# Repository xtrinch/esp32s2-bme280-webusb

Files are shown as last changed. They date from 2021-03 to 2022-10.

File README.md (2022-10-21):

# esp32s2-bme280-webusb

Sends periodic `bme280` humidity, temperature, pressure and battery voltage data from `esp32s2 development board` to [sensor dashboard](http://iotfreezer.com) backend via Wi-Fi. 

Is configurable via a [web interface](http://iotfreezer.com/) using webusb. Since the board uses native usb communication, the serial output will also be emulated via USB so it may not work as you would expect a regular serial connection - if it's configured wrongly, there will be no output in your serial monitor. If the board sleeps, when you connect it to USB, you will not be able to flash it. Board needs to be wide awake and listening to USB commands for flashing to work. When the board is connected to the computer - the neopixel of the esp32s2 will light up and the display should display `PC` instead of the usual measurements.

If you botch the code and manage to put it to sleep when on USB, boot the board into bootloader mode by holding the button `BUT1` on the board when connecting to USB, then you will be able to flash via USB again.

Currently, this firmware can make it around 7 months on a 1200mA battery connected to the dev board. The board can be configured to send the measurements to the server once every N times via the parameter `maxRtcRecords` to optimize battery time.

Built with PlatformIO.

See also [backend](https://github.com/xtrinch/sensor-dashboard-nestjs-backend) and [frontend](https://github.com/xtrinch/sensor-dashboard-react-frontend) repo, or [see it live](http://iotfreezer.com/) with some sensor data from my living room.

## Components
- ESP32S2 dev board with native usb support, meaning there should not be a usb to serial converter on the board, I used [ESP32-S2-DevKit-Lipo-USB from Olimex](https://www.olimex.com/Products/IoT/ESP32-S2/ESP32-S2-DevKit-Lipo-USB/open-source-hardware)
- Waveshare e-paper 1.54inch display - black and white version
- Bosch BME280 sensor module
- 3.7V LiPo battery (or other), e.g. [BATTERY-LIPO1400mAh from Olimex](https://www.olimex.com/Products/Power/BATTERY-LIPO1400mAh/)

## Additional things needed to assemble the PCB
- PH2.0 8 pin connectors for the display (bent needle for the PCB)
- min 2, max 4 2.0mm high spacers to mount the display above the ESP32S2, depending on how many sides of the display you want to fixate
- PH2.0 2pin connector for the battery (if the battery doesn't already come with one)
- bunch of male / female headers
- 1x push button - right angled for RESET button
- 1x push button - regular for BOOT button

## Setup

1. Have a sensor dashboard backend running (see https://github.com/xtrinch/sensor-dashboard-nestjs-backend) or use [iotfreezer](http://iotfreezer.com/).
2. remove the solder from `LED1_ENABLE SMD` jumper (i.e. open it) on the ESP32S2, because it consumes a large current 
3. solder the `BAT_SENS` and `PWR_SENS` jumpers on the ESP32S2, to be able to detect battery voltage levels
4. Uncomment the part in `main.cpp` that routes VREF to a GPIO on the ESP32S2. Program the board, measure VREF and input it into `import_env.py` under `REF_VOLTAGE` (if it's e.g. 1.1, input 1100). This will be needed for accurate battery measurement and you cannot skip this step.
5. Copy `import_env.example.py` to `import_env.py` and define your sensor dashboard url.
6. Run `pio run -t buildfs && pio run -t uploadfs` to upload the icons the display uses for humidity/temperature
7. While having your board plugged into the computer, reboot the board and configure it via the web interface (via webusb) of the sensor dashboard (iotfreezer).

## Troubleshooting

If you cannot upload to your board on linux, input `sudo chmod a+rw /dev/ttyUSB0`.

To monitor across reboots, as uploading and monitoring does not work, use the following command on Linux:
`while [ true ]; do cat /dev/ttyACM0; done`
 
To check out the usb descriptors, run `lsusb -v`. To check out the kernel logs for errors, run `dmesg`.
## Convert icons

 `convert temperature-2-48.png -background white -alpha remove -alpha off -compress none -depth 24 -resize 48x48 temp-final.bmp`

## Production deploy

Make sure to turn off `DEBUG` to save power.

## PCB

See `schematics-w-display` folder for full project. It was drawn in KiCad and it's a two sided PCB.

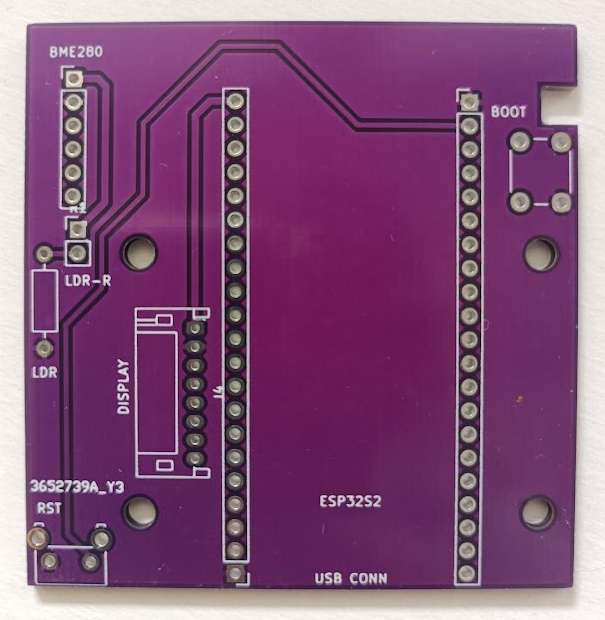
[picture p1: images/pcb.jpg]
Image of Yaktocat


## End product with casing

Casing is parametric and drawn in FreeCad 0.19. It is made to fit the above PCB. For FreeCad project, see `casing-w-display` folder.

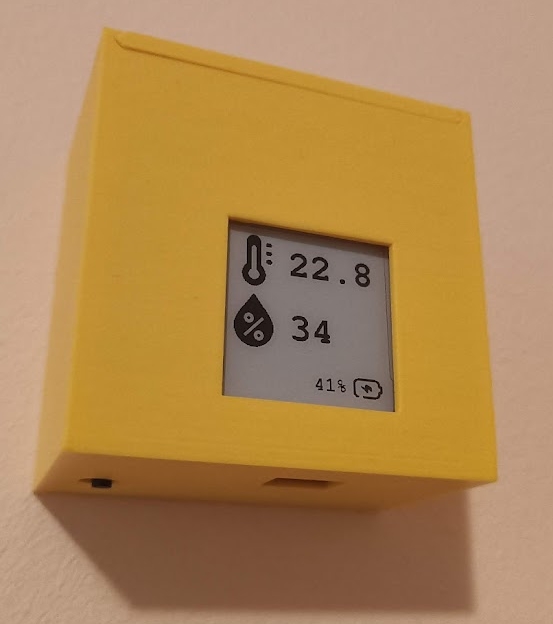
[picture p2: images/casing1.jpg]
Image of Yaktocat

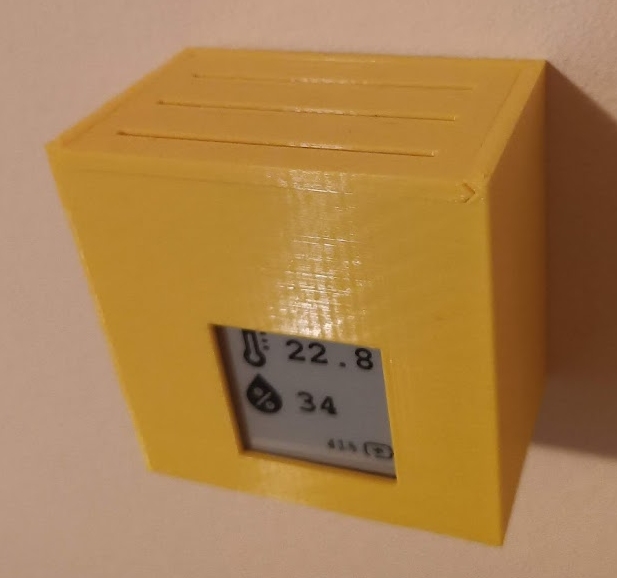
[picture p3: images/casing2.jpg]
Image of Yaktocat


# TODOs
- use ULP to use power pin as ADC wakeup source
- reference ADC voltage to parametrizable params?

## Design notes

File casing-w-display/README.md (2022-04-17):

# parametric display casing

Parametric display casing drawn in FreeCAD.

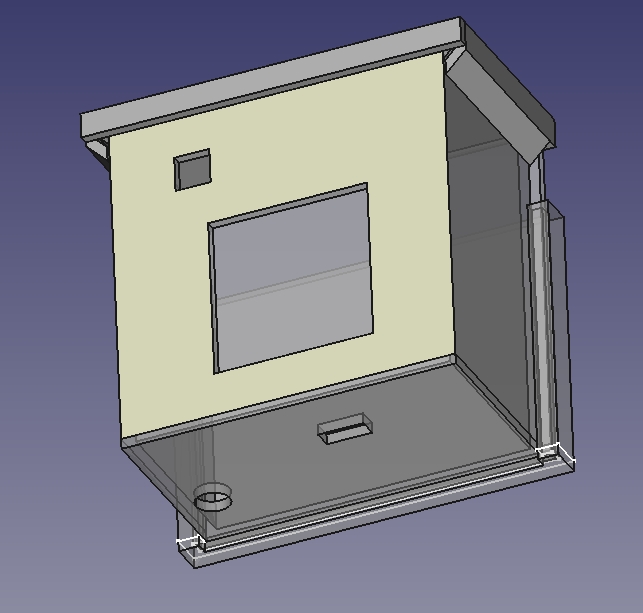
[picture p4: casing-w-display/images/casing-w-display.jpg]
Image of Yaktocat


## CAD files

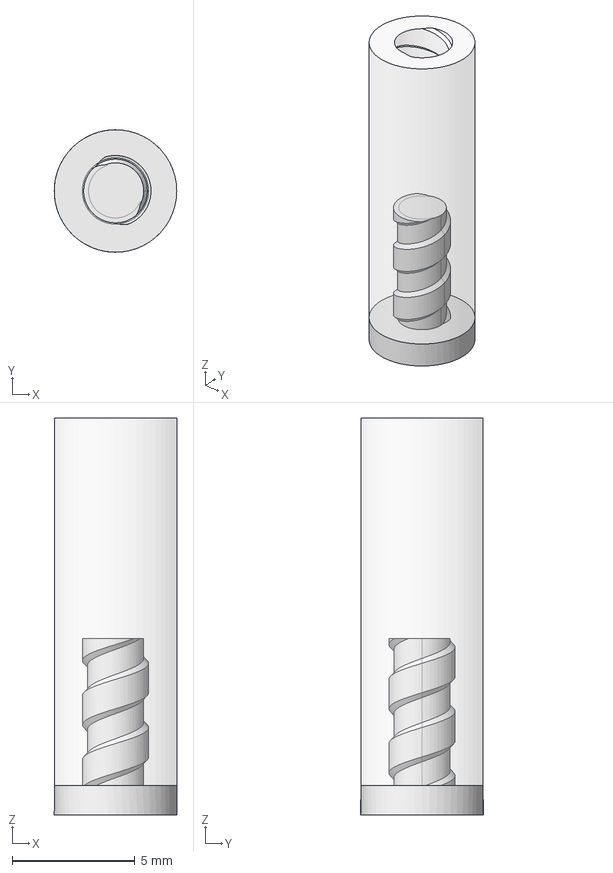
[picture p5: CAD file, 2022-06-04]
casing-w-display/display-spacers.FCStd
5.00 x 5.00 x 16.2 mm
Display spacer
Screw

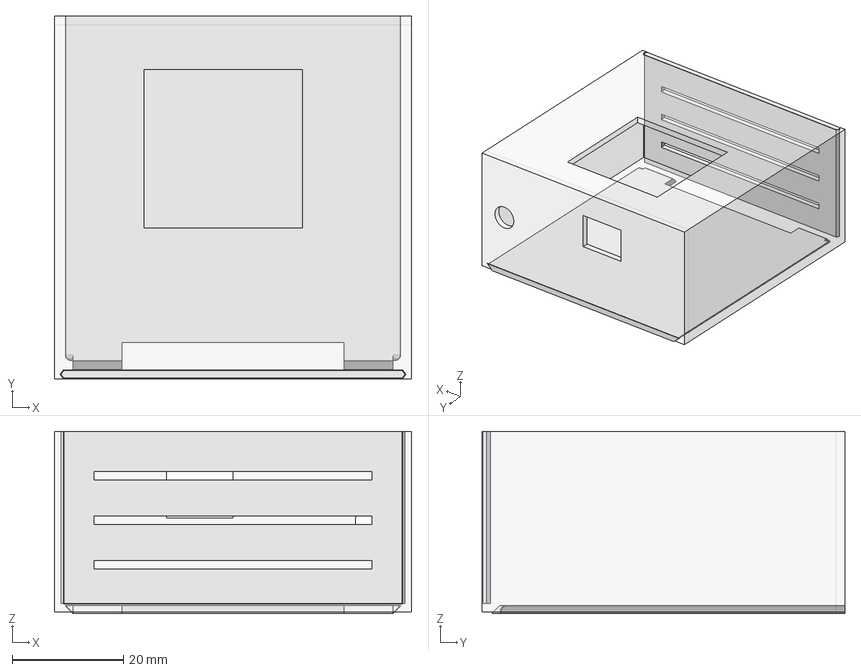
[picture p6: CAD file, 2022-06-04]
casing-w-display/display-casing.FCStd
64.2 x 65.2 x 32.8 mm
Lid
WallMount

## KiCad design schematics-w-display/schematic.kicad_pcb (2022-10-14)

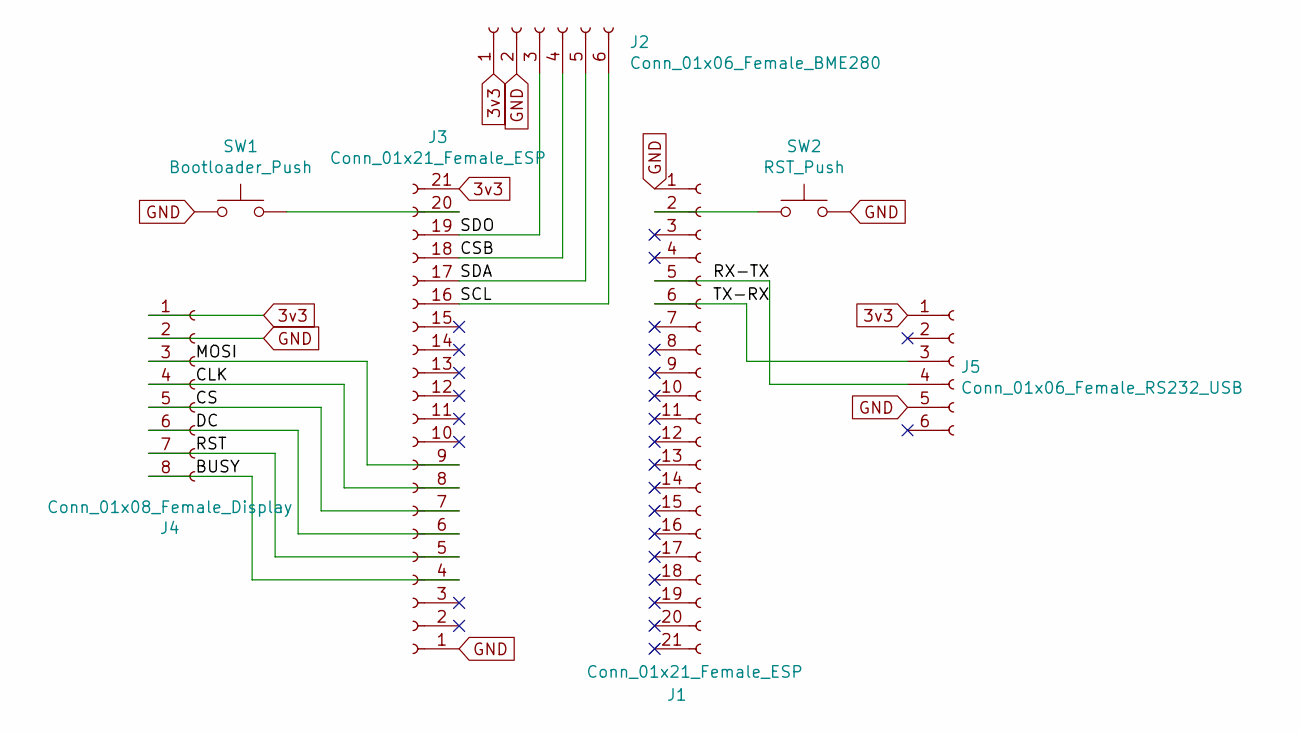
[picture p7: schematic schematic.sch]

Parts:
J1, J3: Conn_01x21_Female_ESP; PinHeader_1x21_P2.54mm_Vertical
J2: Conn_01x06_Female_BME280; PinHeader_1x06_P2.54mm_Vertical
J4: Conn_01x08_Female_Display; JST_PH_S8B-PH-K_1x08_P2.00mm_Horizontal
J5: Conn_01x06_Female_RS232_USB; PinHeader_1x06_P2.54mm_Vertical
SW1: Bootloader_Push; SW_PUSH_6mm
SW2: RST_Push; SW_Tactile_SKHH_Angled

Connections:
3v3: J2.1, J3.21, J4.1, J5.1
/BUSY: J3.4, J4.8
/CLK: J3.8, J4.4
/CS: J3.7, J4.5
/CSB: J2.4, J3.18
/DC: J3.6, J4.6
/MOSI: J3.9, J4.3
/RST: J3.5, J4.7
/RX-TX: J1.5, J5.4
/SCL: J2.6, J3.16
/SDA: J2.5, J3.17
/SDO: J2.3, J3.19
/TX-RX: J1.6, J5.3
GND: J1.1, J2.2, J3.1, J4.2, J5.5, SW1.1, SW2.2
unnamed: J1.2, SW2.1
unnamed: J3.20, SW1.2

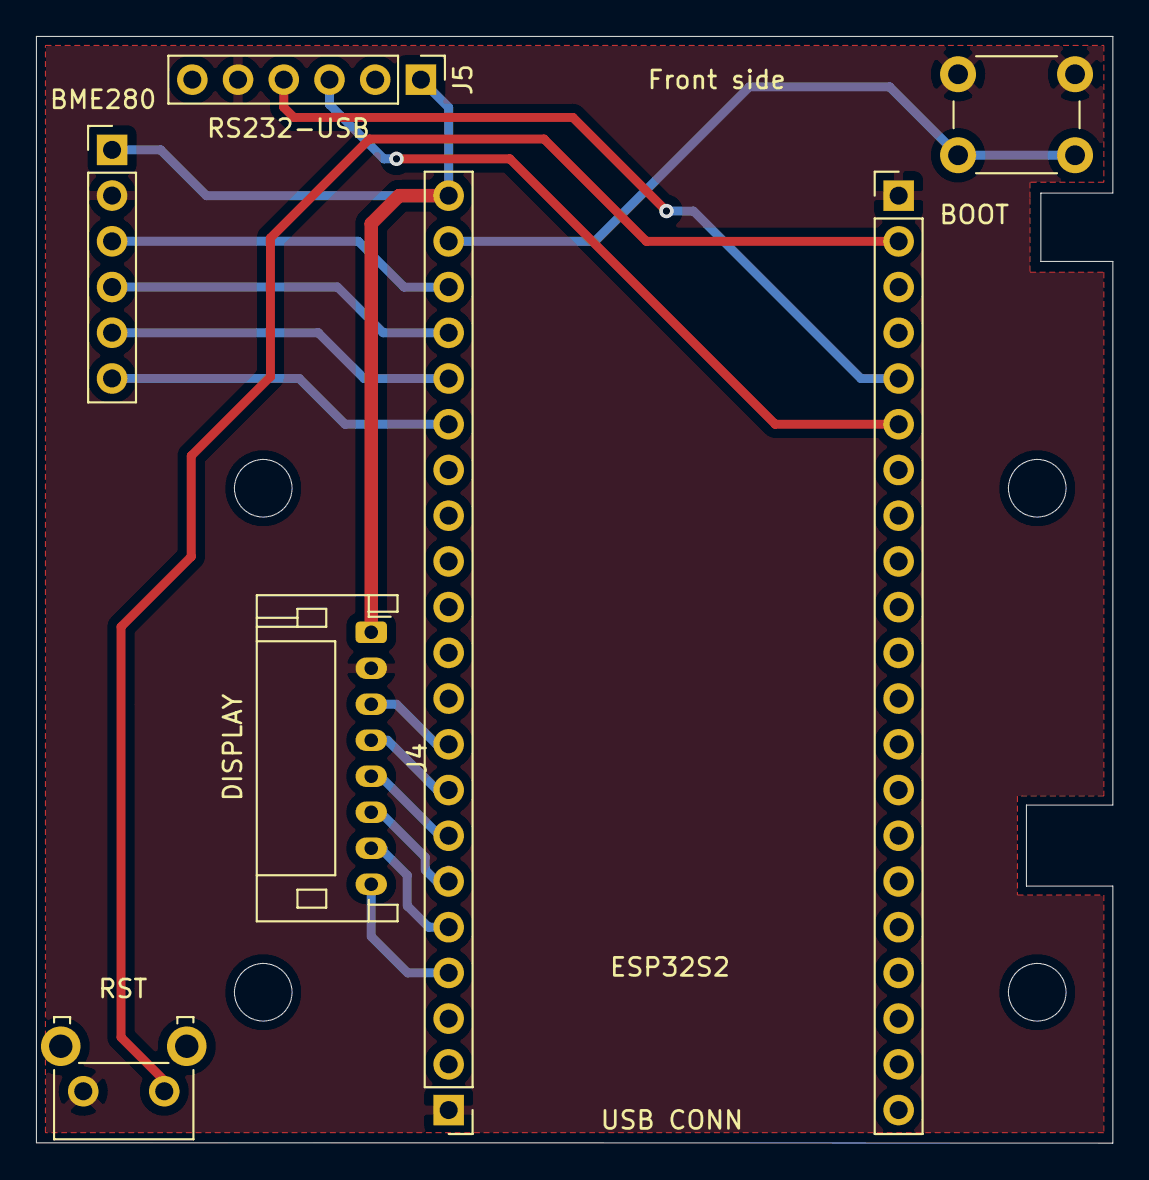
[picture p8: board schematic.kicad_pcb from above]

Board: 2 copper layers, 59.8 x 61.5 mm, 10 parts (0 on the bottom side), 16 nets.

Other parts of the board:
 : MountingHole_3.2mm_M3_DIN965
 #2,  #3: MountingHole_3.2mm_M3_DIN965

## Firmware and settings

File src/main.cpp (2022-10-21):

#include "main.h"
#include "esp_adc_cal.h"

RTC_DATA_ATTR int recordCounter = 0;
RTC_DATA_ATTR bme280record records[100]; // max 100, actual defined by config

#define NEOPIXEL_PIN 18
#define NUMPIXELS 1

Adafruit_NeoPixel pixels(NUMPIXELS, NEOPIXEL_PIN, NEO_GRB + NEO_KHZ800);

WebUSB WebUSBSerial;
CDCusb USBSerial;
Preferences preferences;

volatile bool usbConnected = 0;

// in-sane defaults, which shouldn't be used
// if there's no user configuration anyway
int maxRtcRecords = 1; // always send
int sleepInMinutes = 1; // send once per minute

class MyWebUSBCallbacks: public WebUSBCallbacks {
    void onConnect(bool state) {
      usbConnected = true;
      ardprintf("webusb is %s\n", state ? "connected":"disconnected");
    }
};

class MyCDCUSBCallbacks: public CDCCallbacks {
  // when a serial monitor connects
  bool onConnect(int itf, bool dtr, bool rts) {
    ardprintf("Connected, dtr: %d, rts: %d, itf: %d", dtr, rts, itf);
    usbConnected = true;
    return true;
  }
  void onData() { 
    ardprintf("Received");
    usbConnected = true;
  }
  void onCodingChange(cdc_line_coding_t const* p_line_coding) { 
    ardprintf("C:");
    usbConnected = true;
  }
};

class MyUSBCallbacks: public USBCallbacks {
  void onMount() {
    ardprintf("Mounted");
    usbConnected = true;
  }
};

void sleep(bool forever = false) {
  goToSleep(sleepInMinutes*60, forever);
}

esp_adc_cal_characteristics_t *adc_chars = new esp_adc_cal_characteristics_t;

void setup() {
  WiFi.mode(WIFI_MODE_NULL);

  esp_sleep_wakeup_cause_t wakeup_reason = esp_sleep_get_wakeup_cause();
  bool isReset = wakeup_reason != ESP_SLEEP_WAKEUP_TIMER;

  // this can stay, even if we're not using serial
  Serial.begin(115200);

  USBSerial.setCallbacks(new MyCDCUSBCallbacks());

  WebUSBSerial.landingPageURI("iotfreezer.com", true);
  WebUSBSerial.deviceID(0x2341, 0x0002);
  WebUSBSerial.setCallbacks(new MyWebUSBCallbacks());

  EspTinyUSB::registerDeviceCallbacks(new MyUSBCallbacks());

  if(!USBSerial.begin()) {
    ardprintf("Failed to start USB stack");
    return;
  }

  if(!WebUSBSerial.begin()) {
    ardprintf("Failed to start webUSB stack");
    return;
  }

  pinMode(BAT_SENS_PIN, INPUT_PULLDOWN);
  pinMode(PWR_SENS_PIN, INPUT_PULLDOWN);

  // calibrate the ADC with the measured VREF at 0 attenuation
  adc1_config_width(ADC_WIDTH_BIT_13);
  adc1_config_channel_atten(ADC1_CHANNEL_7, ADC_ATTEN_DB_0); // TODO: channels should be parametrized from pin number
  esp_adc_cal_value_t val_type = 
    esp_adc_cal_characterize(ADC_UNIT_1, ADC_ATTEN_DB_0, ADC_WIDTH_BIT_13, REF_VOLTAGE, adc_chars);

  // IMPORTANT:
  // Uncomment, when you want to route VREF to a GPIO to measure it with a multimeter
  // routeVRefToGPIO(ADC_UNIT_1, GPIO_NUM_17);

  adc1_config_channel_atten(ADC1_CHANNEL_6, ADC_ATTEN_DB_0);
  double rawAdcPower = adc1_get_raw(ADC1_CHANNEL_6);   // read the input pin, 8129 max
  double vPowerMeasured = esp_adc_cal_raw_to_voltage(rawAdcPower, adc_chars);
  double vPower = ((vPowerMeasured/1000.0) * (1000+10000)) / 1000.0; // voltage divider equation
  
  bool connectedToPower = false;
  if (vPower > 3.0) {
    // as an alternative, this could be used for usb connected status, but
    // it would also fire when charging via a regular outlet
    connectedToPower = true;
  }

  double rawAdcBatteryVal = adc1_get_raw(ADC1_CHANNEL_7);
  double vBatMeasured = esp_adc_cal_raw_to_voltage(rawAdcBatteryVal, adc_chars);
  double vBat = ((vBatMeasured/1000.0) * (470000+4700000)) / 470000.0;

  pixels.begin();
  pixels.clear();
  pixels.show();

  if (isCfgSaved()) {
    preferences.begin("iotfreezer", true);
    maxRtcRecords = preferences.getInt("max_rtc_records");
    sleepInMinutes = preferences.getInt("time_between");
    ardprintf("Read max_rtc_records: %d", maxRtcRecords);
    ardprintf("Read time_between: %d", sleepInMinutes);
    preferences.end();
  }

  // wait if usb connection appears - we're supposed to reset the controller when connecting to pc
  // - below 500 won't work
  if ((isReset && ENABLE_USB_CONFIGURATOR)) {
    // we can afford to wait a little longer since we know that the
    // connected to power works well
    delay(1500);
    ardprintf("Connected!. Power is raw %f, measured %f, calculated %f", rawAdcPower, vPowerMeasured, vPower);
    if (usbConnected) {
      if (isCfgSaved()) {
        // green
        pixels.setPixelColor(0, pixels.Color(0, 255, 0)); 
      } else {
        // red
        pixels.setPixelColor(0, pixels.Color(255, 0, 0));
      }
      pixels.show();
      if (ENABLE_DISPLAY) {
        setupDisplay();
        showPcConn();
      }
      // TODO: uncomment
      return; // don't do the measurement
    }
  }

  // TODO: comment out
  // delay(5000);

  ardprintf("Measured battery voltage is %f", vBat);
  if (vBat <= 3.2 && !connectedToPower && !usbConnected) {
    // go to sleep indefinetly, battery is empty
    sleep(true);
  }

  records[recordCounter].battery = (float)vBat;
  records[recordCounter].rawBattery = (float)rawAdcBatteryVal;

  if (!isCfgSaved()) {
    ardprintf("No config saved :(");
    sleep();
  };

  if (!setupbme280()) {
    ardprintf("BME setup is falsch :(");

    // yellow
    pixels.setPixelColor(0, pixels.Color(255, 255, 0));
    pixels.show();

    sleep();
  };

  ardprintf("Measurement %d starting", recordCounter);

  // make a sensor reading
  if (!makeMeasurement(&records[recordCounter])) {
    ardprintf("Failed to perform reading :(");

    // yellow
    pixels.setPixelColor(0, pixels.Color(255, 255, 0));
    pixels.show();

    sleep();
  }

  // save a copy, so we can display the most recent one on the display
  int oldRecordCounter = recordCounter;
  ardprintf("Measurement %d done", recordCounter);
  recordCounter++;

  if (recordCounter < maxRtcRecords) {
    ardprintf("Going to sleep, next up is: %d", recordCounter);
    sleep();
  }
  recordCounter = 0;

  // only refresh display when sending to cloud to save battery
  if (ENABLE_DISPLAY) {
    setupDisplay();
    draw(&records[oldRecordCounter], connectedToPower, sleepInMinutes);
  }

  // everything after this point is just sending the measurement
  // to internet, so it's safe to just return if we're not syncing to
  // the cloud or we're connected to power - because the readings will be
  // far too high to be realistic because charging heats it up
  if (!ENABLE_CLOUD_SYNC || connectedToPower) {
    sleep();
  }

  if (!connectToWifi()) {
    ardprintf("Wi-fi connection failed");
    sleep();
  }

  // around 2000 should be enough for max rtc records = 4
  char jsonPayload[2000];
  getJsonPayload(jsonPayload, records);

  preferences.begin("iotfreezer", true);
  String accessToken = preferences.getString("access_token");
  ardprintf("Read access token: %s", accessToken.c_str());
  preferences.end();

  int httpCode = makeSecureNetworkRequest(
    "https://iotfreezer.com/api/measurements/multi", 
    accessToken.c_str(), 
    jsonPayload, 
    NULL, 
    "POST", 
    IOT_FREEZER_CA_CERT
  );

  ardprintf("API call HTTP code: %d", httpCode);

  WiFi.disconnect(true);
  WiFi.mode(WIFI_OFF);

  sleep();
}

char inputJson[300] = "";
int i = 0;
bool fullWordRead = false;

// only ever come here if we didn't go to sleep in setup - always usb connected
void loop() {
  // read char by char, usually comes in two blocks
  while (WebUSBSerial.available()) {
    char c = WebUSBSerial.read();

    // stop character is 0, everything else is the input json
    if (c != 0) {
      inputJson[i] = c;
      i++;
    } else {
      inputJson[i] = '\0';
      i = 0;
      fullWordRead = true;
    }
  }

  if (fullWordRead) {
    USBSerial.write((uint8_t *)inputJson, strlen(inputJson));
    USBSerial.write('\n');

    DynamicJsonDocument doc(1024);
    deserializeJson(doc, inputJson);
    JsonObject obj = doc.as<JsonObject>();
    bool configSaved = saveCfg(
      obj["wifiSSID"], 
      obj["wifiPassword"], 
      obj["accessToken"],
      obj["timeBetweenMeasurements"].as<uint8_t>(),
      obj["maxRtcRecords"].as<uint8_t>()
    );

    // recheck, just in case
    if (configSaved && isCfgSaved()) {
      // blue, so we know we've configured it even if it was already configured
      pixels.setPixelColor(0, pixels.Color(0, 0, 255));
      pixels.show();
      WebUSBSerial.write((uint8_t *)"success", strlen("success"));
    } else {
      WebUSBSerial.write((uint8_t *)"failure", strlen("failure"));
    }

    inputJson[0] = '\0';
    fullWordRead = false;
  }
}

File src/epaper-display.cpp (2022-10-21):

#include "epaper-display.h"

#include <SPIFFS.h>

#include <GxEPD2_BW.h>
#include <GxEPD2_3C.h>
#include <Fonts/FreeMonoBold24pt7b.h>
#include <Fonts/FreeMonoBold12pt7b.h>
#include "GxEPD2_display_selection_new_style.h"
#include "bitmaps/Bitmaps200x200.h" // 1.54" b/w

static const uint16_t input_buffer_pixels = 800; // may affect performance

static const uint16_t max_row_width = 1448; // for up to 6" display 1448x1072
static const uint16_t max_palette_pixels = 256; // for depth <= 8

uint8_t input_buffer[3 * input_buffer_pixels]; // up to depth 24
uint8_t output_row_mono_buffer[max_row_width / 8]; // buffer for at least one row of b/w bits
uint8_t output_row_color_buffer[max_row_width / 8]; // buffer for at least one row of color bits
uint8_t mono_palette_buffer[max_palette_pixels / 8]; // palette buffer for depth <= 8 b/w
uint8_t color_palette_buffer[max_palette_pixels / 8]; // palette buffer for depth <= 8 c/w
uint16_t rgb_palette_buffer[max_palette_pixels]; // palette buffer for depth <= 8 for buffered graphics, needed for 7-color display


void setupDisplay() {
  display.init();

  display.setRotation(1);
  SPIFFS.begin();
}

uint16_t read16(fs::File& f)
{
  // BMP data is stored little-endian, same as Arduino.
  uint16_t result;
  ((uint8_t *)&result)[0] = f.read(); // LSB
  ((uint8_t *)&result)[1] = f.read(); // MSB
  return result;
}

uint32_t read32(fs::File& f)
{
  // BMP data is stored little-endian, same as Arduino.
  uint32_t result;
  ((uint8_t *)&result)[0] = f.read(); // LSB
  ((uint8_t *)&result)[1] = f.read();
  ((uint8_t *)&result)[2] = f.read();
  ((uint8_t *)&result)[3] = f.read(); // MSB
  return result;
}

void drawBitmapFromSpiffs(const char *filename, int16_t x, int16_t y, bool with_color = false)
{
  fs::File file;
  bool valid = false; // valid format to be handled
  bool flip = true; // bitmap is stored bottom-to-top
  uint32_t startTime = millis();
  if ((x >= display.epd2.WIDTH) || (y >= display.epd2.HEIGHT)) return;
  ardprintf("\n");
  ardprintf("Loading image '");
  ardprintf(filename);
#if defined(ESP32)
  file = SPIFFS.open(String("/") + filename, "r");
#else
  file = SPIFFS.open(filename, "r");
#endif
  if (!file)
  {
    ardprintf("File not found");
    return;
  }
  // Parse BMP header
  uint16_t signature = read16(file);
  if (signature == 0x4D42) // BMP signature
  {
    ardprintf("Read BMP signature");
    uint32_t fileSize = read32(file);
    uint32_t creatorBytes = read32(file);
    uint32_t imageOffset = read32(file); // Start of image data
    uint32_t headerSize = read32(file);
    uint32_t width  = read32(file);
    uint32_t height = read32(file);
    uint16_t planes = read16(file);
    uint16_t depth = read16(file); // bits per pixel
    uint32_t format = read32(file);
    ardprintf("Format");
    ardprintf("%d \n", format);
    if ((planes == 1) && ((format == 0) || (format == 3))) // uncompressed is handled, 565 also
    {
      ardprintf("File size: "); ardprintf("%d \n", fileSize);
      ardprintf("Image Offset: "); ardprintf("%d \n", imageOffset);
      ardprintf("Header size: "); ardprintf("%d \n", headerSize);
      ardprintf("Bit Depth: "); ardprintf("%d \n", depth);
      ardprintf("Image size: ");
      ardprintf("%d", width);
      ardprintf("x");
      ardprintf("%d", height);
      // BMP rows are padded (if needed) to 4-byte boundary
      uint32_t rowSize = (width * depth / 8 + 3) & ~3;
      if (depth < 8) rowSize = ((width * depth + 8 - depth) / 8 + 3) & ~3;
      if (height < 0)
      {
        height = -height;
        flip = false;
      }
      uint16_t w = width;
      uint16_t h = height;
      if ((x + w - 1) >= display.epd2.WIDTH)  w = display.epd2.WIDTH  - x;
      if ((y + h - 1) >= display.epd2.HEIGHT) h = display.epd2.HEIGHT - y;
      if (w <= max_row_width) // handle with direct drawing
      {
        valid = true;
        uint8_t bitmask = 0xFF;
        uint8_t bitshift = 8 - depth;
        uint16_t red, green, blue;
        bool whitish, colored;
        if (depth == 1) with_color = false;
        if (depth <= 8)
        {
          if (depth < 8) bitmask >>= depth;
          //file.seek(54); //palette is always @ 54
          file.seek(imageOffset - (4 << depth)); // 54 for regular, diff for colorsimportant
          for (uint16_t pn = 0; pn < (1 << depth); pn++)
          {
            blue  = file.read();
            green = file.read();
            red   = file.read();
            file.read();
            whitish = with_color ? ((red > 0x80) && (green > 0x80) && (blue > 0x80)) : ((red + green + blue) > 3 * 0x80); // whitish
            colored = (red > 0xF0) || ((green > 0xF0) && (blue > 0xF0)); // reddish or yellowish?
            if (0 == pn % 8) mono_palette_buffer[pn / 8] = 0;
            mono_palette_buffer[pn / 8] |= whitish << pn % 8;
            if (0 == pn % 8) color_palette_buffer[pn / 8] = 0;
            color_palette_buffer[pn / 8] |= colored << pn % 8;
          }
        }
        // display.clearScreen();
        uint32_t rowPosition = flip ? imageOffset + (height - h) * rowSize : imageOffset;
        for (uint16_t row = 0; row < h; row++, rowPosition += rowSize) // for each line
        {
          uint32_t in_remain = rowSize;
          uint32_t in_idx = 0;
          uint32_t in_bytes = 0;
          uint8_t in_byte = 0; // for depth <= 8
          uint8_t in_bits = 0; // for depth <= 8
          uint8_t out_byte = 0xFF; // white (for w%8!=0 border)
          uint8_t out_color_byte = 0xFF; // white (for w%8!=0 border)
          uint32_t out_idx = 0;
          file.seek(rowPosition);
          for (uint16_t col = 0; col < w; col++) // for each pixel
          {
            // Time to read more pixel data?
            if (in_idx >= in_bytes) // ok, exact match for 24bit also (size IS multiple of 3)
            {
              in_bytes = file.read(input_buffer, in_remain > sizeof(input_buffer) ? sizeof(input_buffer) : in_remain);
              in_remain -= in_bytes;
              in_idx = 0;
            }
            switch (depth)
            {
              case 24:
                blue = input_buffer[in_idx++];
                green = input_buffer[in_idx++];
                red = input_buffer[in_idx++];
                whitish = with_color ? ((red > 0x80) && (green > 0x80) && (blue > 0x80)) : ((red + green + blue) > 3 * 0x80); // whitish
                colored = (red > 0xF0) || ((green > 0xF0) && (blue > 0xF0)); // reddish or yellowish?
                break;
              case 16:
                {
                  uint8_t lsb = input_buffer[in_idx++];
                  uint8_t msb = input_buffer[in_idx++];
                  if (format == 0) // 555
                  {
                    blue  = (lsb & 0x1F) << 3;
                    green = ((msb & 0x03) << 6) | ((lsb & 0xE0) >> 2);
                    red   = (msb & 0x7C) << 1;
                  }
                  else // 565
                  {
                    blue  = (lsb & 0x1F) << 3;
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

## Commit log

2020-10-11 I2c address to cfg
2021-01-06 Esp32s2 support, I2C->SPI
2021-03-13 Add schematics for ESP32S2
    [schematic.kicad_pcb, schematic.sch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]
2021-03-19 Kicad schematics
    [schematic.kicad_pcb]
2021-04-19 Remove old schematics
    [schematic.kicad_pcb, schematic.sch]
2021-04-19 EEPROM Addresses bugfixes; working version
    [main.cpp]
2021-05-05 Update branch of arduino-esp23 as alpha support for esp32s2 has been added
2021-05-08 Some battery sensing code
2021-05-10 Send battery to server
2021-05-10 Fix battery calibration value
    [main.cpp]
2021-06-07 Update battery sensing measurements
2021-06-07 ADC calibration: success
2021-06-11 Battery indicator
2021-07-11 Initial version of schematics
    [schematic.kicad_pcb, schematic.sch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]
2021-07-11 Version 2
    [schematic.kicad_pcb]
2021-07-13 Final version
    [schematic.kicad_pcb]
2021-07-14 Maybe not so final version
    [schematic.kicad_pcb, schematic.sch]
2021-07-14 Final version: again
    [schematic.kicad_pcb]
2021-08-01 Power indicator: works
2021-08-06 Fix battery percentage display
    [common.cpp, epaper-display.cpp, main.cpp]
2021-09-03 Some schematic prettify
    [schematic.kicad_pcb, schematic.sch]
2021-09-03 Add LDR to schematic
    [schematic.kicad_pcb, schematic.sch]
2021-09-03 Use resistor as footprint for resistor
    [schematic.kicad_pcb]
2022-03-29 Some schematic
    [schematic.sch]
2022-03-29 New version of display pcb
    [schematic-B_Cu.gbr, schematic-B_Mask.gbr, schematic-B_SilkS.gbr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]
2022-04-04 Minor changes
    [schematic.kicad_pcb]
2022-04-17 Add casing
    [display-casing.FCStd, sdb-display-casing.3mf, sdb-display-casing.stl]
2022-04-20 Some more schematics
    [display-casing.FCStd, lid-v1.stl, lid.stl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]
2022-04-22 Air holes + move stuff around
    [body.stl, display-casing.FCStd, lid-v2.stl]
2022-04-23 Flat lid
    [body.stl, display-casing.FCStd, lid-v1.stl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]
2022-04-24 Boxed version: OK
    [display-casing.FCStd, sdb-display-casing-v5.stl]
2022-04-24 Minor aux fixes + display w/h
    [display-casing.FCStd]
2022-04-24 Chamfer the non-printable back
    [display-casing.FCStd]
2022-04-24 Update to freecad 0.19
    [display-casing.FCStd]
2022-04-24 Further decrease display wdth
    [display-casing.FCStd]
2022-04-24 V6 final
    [display-casing.FCStd, sdb-display-casing-v4.3mf, sdb-display-casing-v4.stl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]
2022-04-25 After yellow print: Fix the back floating chamfer
    [display-casing.FCStd]
2022-04-29 Casing v8
    [display-casing-v8.stl, display-casing.FCStd, sdb-display-casing-v5.stl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]
2022-05-10 Minor fixes
    [sdb-display-casing.3mf]
2022-05-10 Fix for the new displays and hope it still works for old ones
    [epaper-display.cpp]
2022-05-12 Final spacer version
    [display-spacers-Display spacer.stl, display-spacers.FCStd]
2022-05-13 More readme
    [display-spacers-Display spacer.3mf]
2022-05-13 Decrease height of bo
    [display-casing.FCStd]
2022-05-13 0.1 increase of box wall mount
    [display-casing.FCStd]
2022-05-13 Initial print
    [display-casing.FCStd, display-casing1.stl]
2022-05-13 Back slider different type
    [display-casing.FCStd]
2022-05-13 Fitting back
    [display-casing.FCStd]
2022-05-15 Fitting back 2
    [display-casing.FCStd]
2022-05-15 Fitting back 3
    [display-casing.FCStd]
2022-05-15 Fitting back 4
    [display-casing.FCStd]
2022-05-15 Print version
    [display-casing.FCStd, display-casing1.stl]
2022-05-15 Obj height -0.5mm, lid length -0.1mm
    [display-casing.FCStd]
2022-05-21 Something something
    [display-casing.FCStd]
2022-05-22 Fix box height
    [display-casing.FCStd]
2022-05-22 Skip cloud connection when charging because readings will be off
    [main.cpp]
2022-06-04 Thinner version with small headers
    [display-casing.FCStd, display-spacers.FCStd]
2022-06-06 Move boot button up
    [schematic.kicad_pcb]
2022-06-06 Add additional cable hole
    [schematic.kicad_pcb]
2022-06-13 Remove LDR, add serial converter
    [schematic.kicad_pcb, schematic.sch]
2022-10-14 Some last schematic changes
    [schematic-B_Cu.gbr, schematic-B_Mask.gbr, schematic-B_SilkS.gbr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]
2022-10-14 Put the controller to sleep when battery < 3.2
